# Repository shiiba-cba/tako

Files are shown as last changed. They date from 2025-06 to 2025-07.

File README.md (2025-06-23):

# tako

**tako** は、55 mm の大玉ボールを 624ZZ ベアリング 3 点支持で滑らかに駆動し、PMW3360 光学センサーと RP2040‏-Zero MCU による高精度トラッキングを備えた自作 6 ボタン・トラックボールです。アーケードコントローラー用ゲームスイッチの硬質なクリック感を持つボタンはボールの手前に配置されているため、指をボールから離さずにクリックやドラッグが可能。標準搭載のドラッグスクロール、スクロール方向切替、CPI 切替え機能により、ウェブブラウジングから CAD・DTP などの精密操作まで幅広く快適に扱えます。

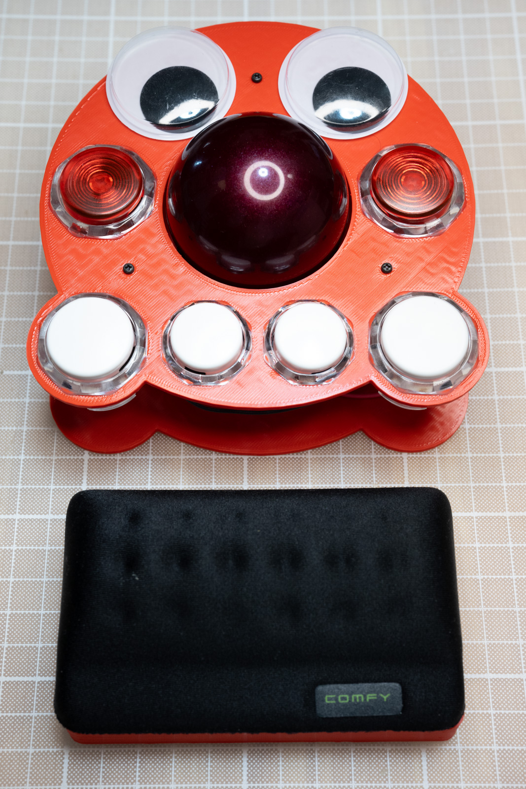
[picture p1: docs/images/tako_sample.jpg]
tako


---

## 🔧 特徴

* ボール: **55 mm径ボール**（PERIPRO-304など）
* 光学センサー: **PMW3360**（SPI）
* マイコン: **RP2040-Zero**（USB-C）
* 支持機構: **624ZZ ベアリング x3**
* ボタン: 6 ボタン（アーケードコントローラー用ゲームスイッチ 30mm×4, 24mm×2）
* ファームウェア: **QMK Firmware** ベース
* **CPI_TGL** キーコードによる CPI 切り替え（600 ↔ 200 CPI）  
  *デフォルト操作*: DRAG_SCROLL ボタンを押しながら左クリック
* **SCRL_MODE** キーコードによるスクロール方向切替（XY → Y のみ → X のみ）  
  *デフォルト操作*: DRAG_SCROLL ボタンを押しながら戻るボタン  
* ドラッグスクロール対応（XY / Y / X モード）

---

## 📦 含まれるもの

* `firmware/`: QMK ファームウェアソースおよびビルド済み `.uf2`
* `case/`: 3D プリント用 STL ファイル
* `docs/build_guide.md`: ビルドガイド（日本語）

---

## 📘 ビルドガイド

👉 [ビルドガイドはこちら](docs/build_guide.md)

---

## 🧑‍💻 ファームウェア書き込み（簡易手順）

1. RP2040-Zero の **BOOT** ボタンを押しながら USB 接続
2. 表示される `RPI-RP2` ドライブに `.uf2` ファイルをコピー
3. 自動で再起動し、USB HID デバイスとして認識されたら完了

---

## 📜 ライセンス

MIT License
Copyright © 2025 shiiba

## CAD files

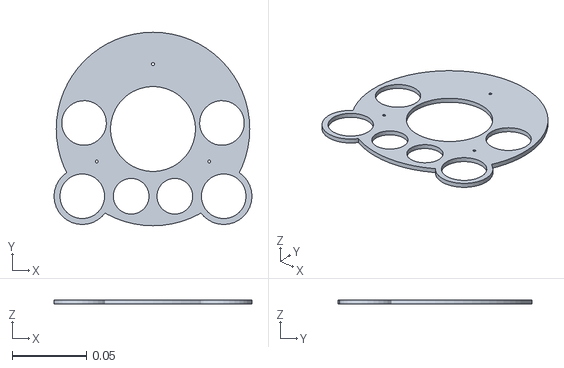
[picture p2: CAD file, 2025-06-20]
case/stl/624ZZ/tako_top_624ZZ.stl
0.133 x 0.13 x 0.003

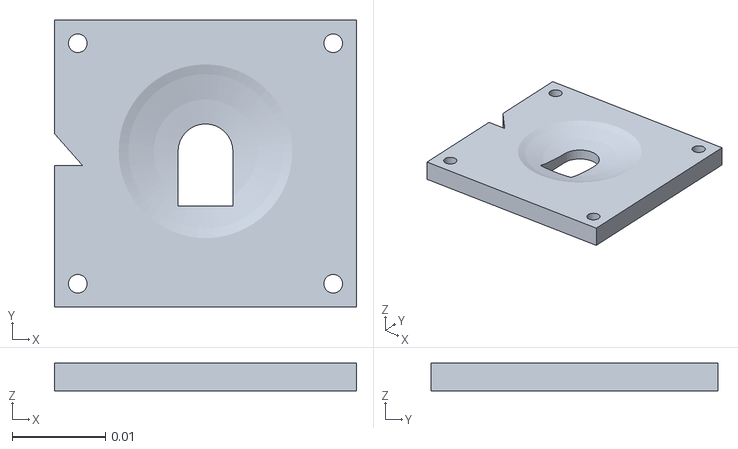
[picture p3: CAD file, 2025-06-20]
case/stl/tako_sensorcover.stl
0.0324 x 0.0308 x 0.003

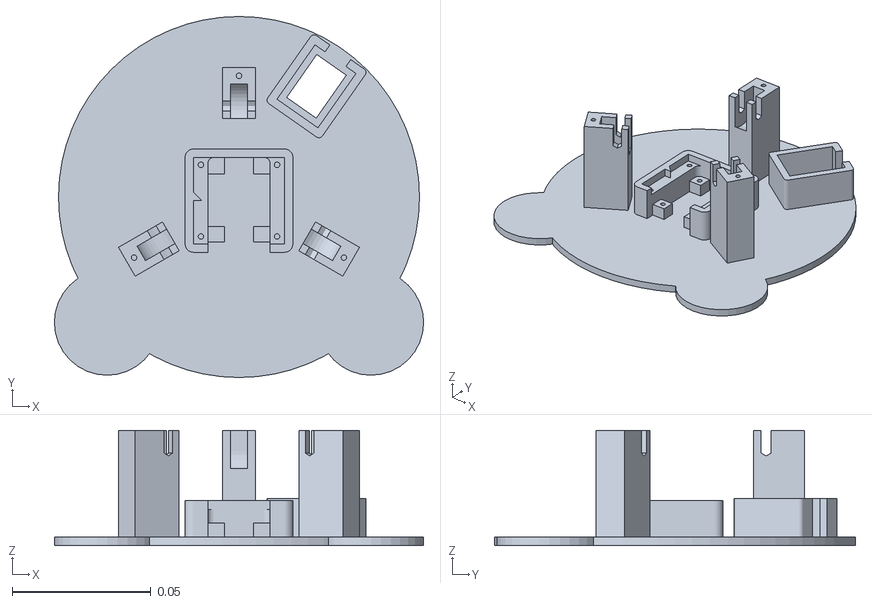
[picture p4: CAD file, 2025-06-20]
case/stl/624ZZ/tako_bottom_624ZZ.stl
0.133 x 0.13 x 0.0415

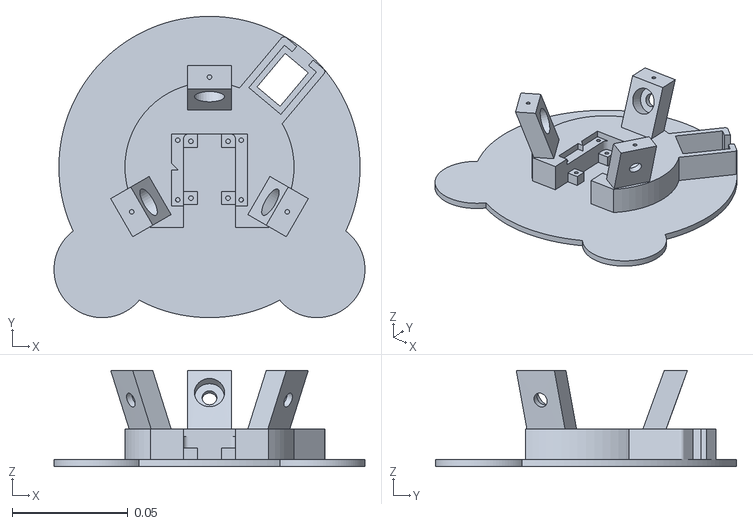
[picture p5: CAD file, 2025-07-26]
case/stl/R053010810/tako_bottom_R053010810.stl
0.134 x 0.13 x 0.0415

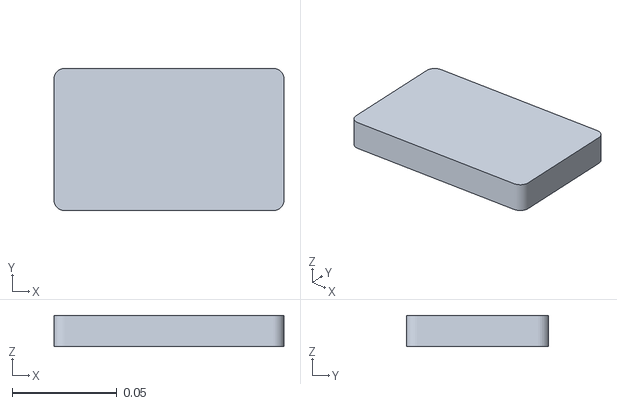
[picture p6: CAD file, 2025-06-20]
case/stl/tako_wristrest_15mm.stl
0.11 x 0.068 x 0.015

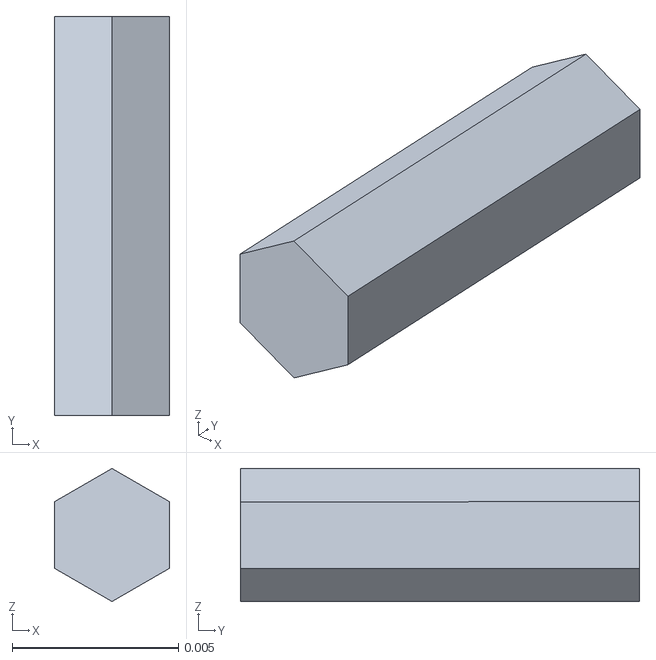
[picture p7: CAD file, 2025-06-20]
case/stl/624ZZ/tako_bearingshaft_624ZZ.stl
0.00346 x 0.012 x 0.004

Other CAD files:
case/stl/R053010810/tako_top_R053010810.stl

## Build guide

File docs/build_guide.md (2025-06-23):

# tako ビルドガイド

---

## 目次

1. [仕様概要](#1-仕様概要)
2. [必要なもの](#2-必要なもの)
3. [3D プリント設定](#3-3d-プリント設定)
4. [配線図](#4-配線図)
5. [組立手順](#5-組立手順)
6. [ファームウェア書き込み](#6-ファームウェア書き込み)
7. [動作確認](#7-動作確認)
8. [参考・謝辞](#8-参考・謝辞)
9. [ライセンス & コピーライト](#9-ライセンス--コピーライト)

---

## 1. 仕様概要

| 項目 | 内容 |
| --- | --- |
| ボール径 | **55 mm** |
| センサー | **PMW3360**（SPI 接続） |
| MCU | **RP2040‑Zero**（USB‑C） |
| ベアリング | **624ZZ** × 3（内径 4 mm / 外径 13 mm / 幅 5 mm） |
| ボタン | 6 ボタン (⌀30 mm × 4、⌀24 mm × 2) |
| ケース | 3D プリント（STL 同梱） |

---

## 2. 必要なもの
ブレイクアウト基板と3D プリント部品を除き、すべて市販品で構成されています。

### 2‑1. 電子部品

| 区分 | 品名／型番 | 個数 | 備考 |
| --- | --- | ---- | --- |
| **センサー** | **PMW3360 本体** | 1 | — |
| **ブレイクアウト基板** | **PMW3360 breakout board** | 1 | [https://github.com/jfedor2/pmw3360-breakout](https://github.com/jfedor2/pmw3360-breakout) |
| **MCU** | **RP2040‑Zero** | 1 | USB‑C |

### 2‑2. 機構部品

| 区分 | 品名 | 個数 | 備考 |
| --- | --- | ---- | --- |
| **ベアリング** | **624ZZ** | 3 | — |
| **ボタン (⌀30 mm)** | はめ込み式ゲームスイッチ | 4 | 例: GamerFinger NEW‑HBFS‑30 |
| **ボタン (⌀24 mm)** | はめ込み式ゲームスイッチ | 2 | 例: GamerFinger NEW‑HBFS‑24 |
| **ボール** | **55 mm** | 1 | 例: PERIXX PERIPRO‑304 |
| **ネジ** | M2×4 | 4 | ブレイクアウト基板固定 |
| 〃 | M2×6 | 7 | センサーカバー 4、本体 3 |
| **3D プリント部品 (STL)** | `tako_bearingshaft_624ZZ.stl` | 3 | ベアリングシャフト |
| | `tako_bottom_624ZZ.stl` | 1 | ボトムケース |
| | `tako_sensorcover.stl` | 1 | センサーカバー |
| | `tako_top_624ZZ.stl` | 1 | トップケース |
| | `tako_wristrest_15mm.stl` | 1 | （任意）リストレスト台座 |
| **リストレスト (任意)** | ELECOM COMFY MOH‑013BK | 1 | — |
| **両面テープ (任意)** | — | 適量 | リストレスト固定用 |
| **滑り止めパッド (任意)** | — | 適量 | 本体およびリストレスト台座の底面貼付・傾斜調整用 |
| **目玉シール (任意)** | 30–40 mm | 2 | トップケース装飾用 |

### 2‑3. コネクタ／ハウジング／ケーブル

| 区分 | 型番 | 個数 | 用途 |
| --- | --- | --- | --- |
| **コンタクトピン** | **QI2550 圧着端子** | 15 以上 | 予備を含め多めに準備 |
| **ハウジング 1P** | **QI2550 1P** | 5 | GND, 3V3 など |
| **ハウジング 3P** | **QI2550 3P** | 2 | 各ボタン → MCU |
| **ハウジング 4P** | **QI2550 4P** | 1 | センサー → MCU |
| **ピンヘッダー** | **1×3 (2.54 mm)** | 1 | GND 共通化用 |
| **圧着端子** | **Faston #110 (L型 / 絶縁ケース付 推奨)** | 12 以上 | ボタンスイッチ接続 |
| **ケーブル** | **AWG24 配線** | 適量 | — |
| **絶縁テープ** | — | 適量 | ピンヘッダー保護 |
| **熱収縮チューブ (任意)** | — | 適量 | ケーブル保護・束線用 |

### 2‑4. 工具

| 区分 | 名称 | 用途 |
| --- | --- | --- |
| 造形 | **3D プリンタ (FDM)** | ケース・ベアリングシャフト造形 |
| 基板実装 | 半田ごて + はんだ | センサー・ヘッダー実装 |
| 配線加工 | ニッパー | ケーブル長調整 |
| 圧着 | Faston 圧着工具 | ボタン用 Faston #110 |
| 〃 | QI2550 圧着工具 | コネクタ結線 |
| 仕上げ | プラスドライバー | M2 ネジ締結 |

---

## 3. 3D プリント設定

| パーツ | 素材 | レイヤー高 | インフィル |
| --- | ---- | --- | --- |
| すべて | PLA  | 0.20 mm | 15 % グリッド |

---

## 4. 配線図

### 4‑1. センサー

| PMW3360 | RP2040‑Zero  |
| --- | --- |
| SCLK | GPIO2 |
| MOSI | GPIO3 |
| MISO | GPIO4 |
| NCS | GPIO5 |
| 3V3 | 3V3 OUT |
| GND | GND |

### 4‑2. ボタン割り当て（デフォルト）

| ボタン | RP2040‑Zero GPIO |
| --- | --- |
| 左ボタン | GPIO14 |
| 右ボタン | GPIO27 |
| ミドルボタン | GPIO15 |
| 戻るボタン | GPIO26 |
| 進むボタン | GPIO29 |
| ドラッグスクロールボタン | GPIO28 |

### 4‑3. CPI_TGL キーコードとデフォルト操作

- **初期 CPI**: 600
- **キーコード**: `CPI_TGL`
- **デフォルト操作**: DRAG_SCROLL ボタン(GPIO28)を押しながら左ボタン(GPIO14)を押すと `CPI_TGL` が送出され、CPI が 600 ↔ 200 に切り替わります。

### 4‑4. SCRL_MODE キーコードとスクロール方向切替

`SCRL_MODE` を押すたびにスクロールモードが **XY** → **Y のみ** → **X のみ** → **XY** ... の順に循環します。
- **キーコード**: `SCRL_MODE`
- **デフォルト操作**: DRAG_SCROLL ボタン(GPIO28)を押しながら戻るボタン(GPIO26)を押すと `SCRL_MODE` が送出され、スクロール方向が切り替わります。

---

## 5. 組立手順

1. **ブレイクアウト基板の準備**  
   **PMW3360** をブレイクアウト基板へ実装し、各ピンにリード線をはんだ付けします。  
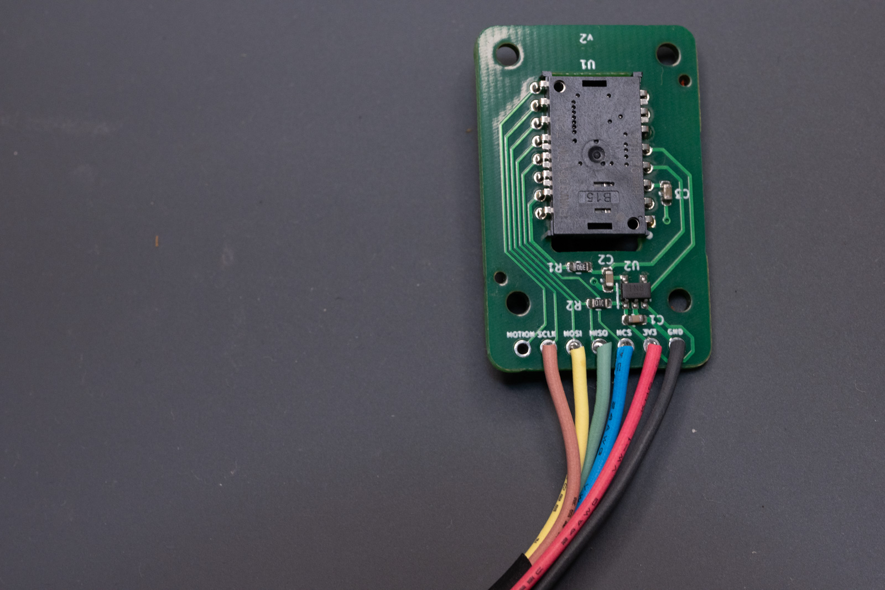
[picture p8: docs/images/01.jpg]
     
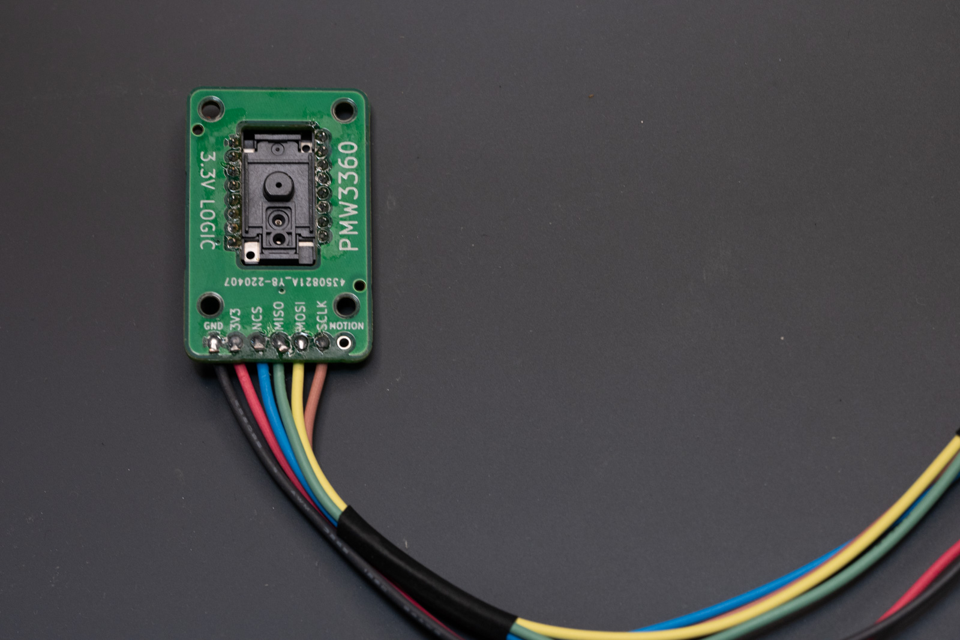
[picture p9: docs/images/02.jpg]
   
2. **GND 共通化用ピンヘッダーの準備**  
   ボタン GND をまとめるために **1×3 ピンヘッダー (2.54 mm)** をハンダブリッジして 3 ピンを共通化した "GND バス" を自作します。
   ブリッジ部は **絶縁テープ** を巻いてショートを防止します。  
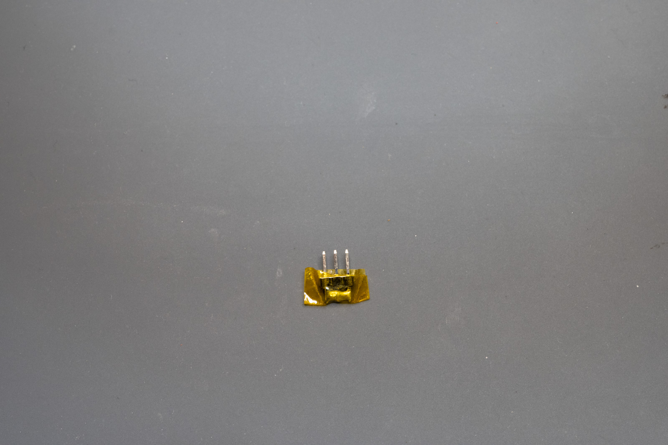
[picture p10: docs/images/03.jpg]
   
3. **ボトムケースへのセンサー固定**  
   ブレイクアウト基板を `tako_bottom_624ZZ.stl` に収め、M2×4 ネジ×4 で固定。  
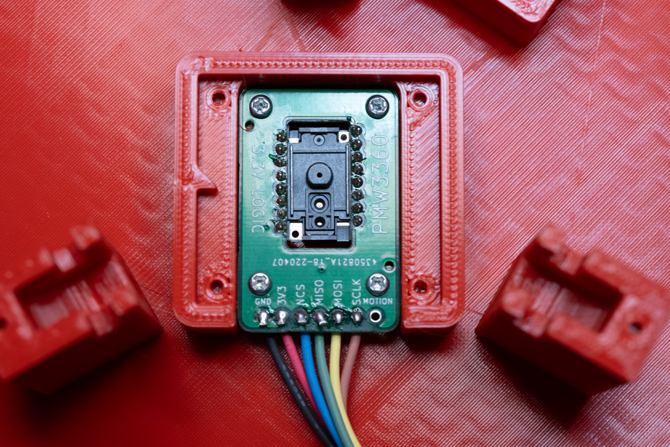
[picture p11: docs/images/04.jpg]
   
4. **レンズ & センサーカバー**  
   レンズを装着後、`tako_sensorcover.stl` を被せて M2×6 ネジ×4 で固定。  
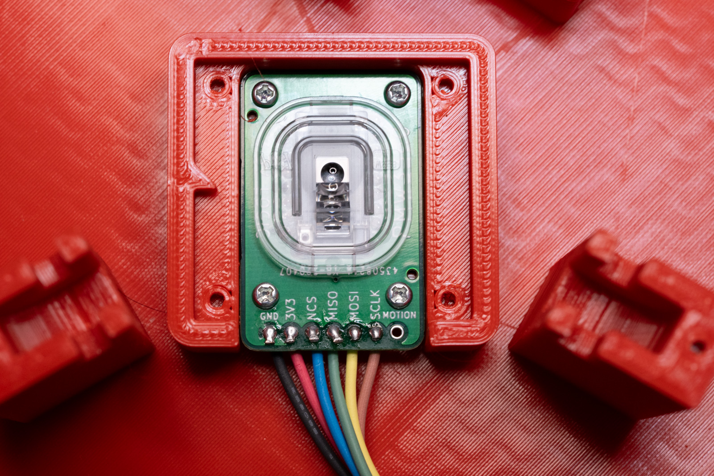
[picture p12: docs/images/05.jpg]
     
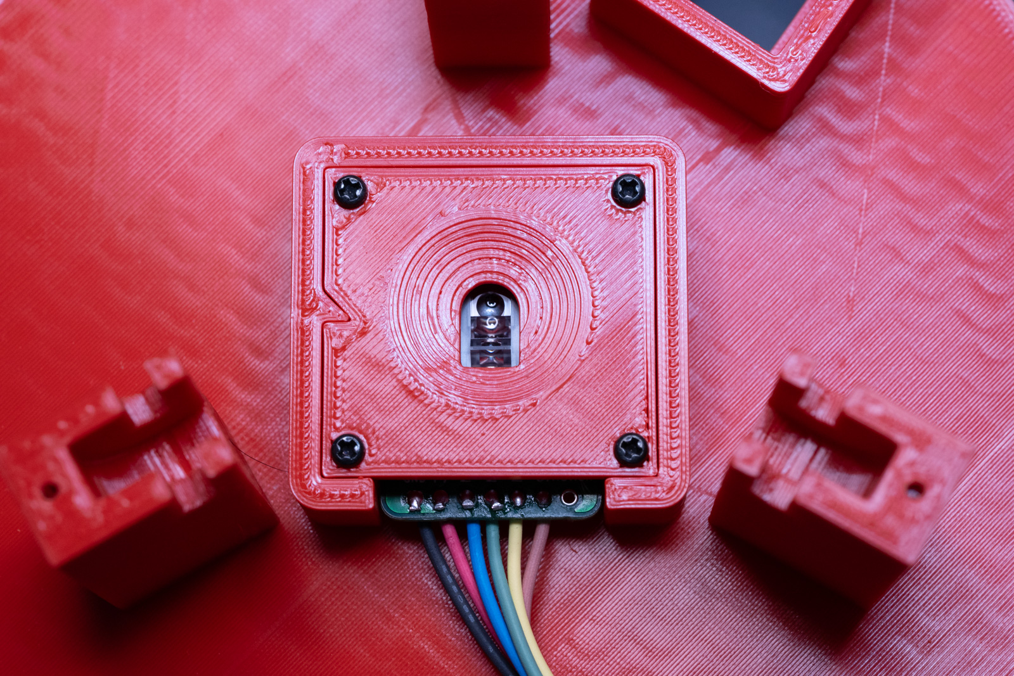
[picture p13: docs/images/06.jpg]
   
5. **ベアリングユニット作成**  
   **624ZZ** に `tako_bearingshaft_624ZZ.stl` を差し込み、3 つ用意。  
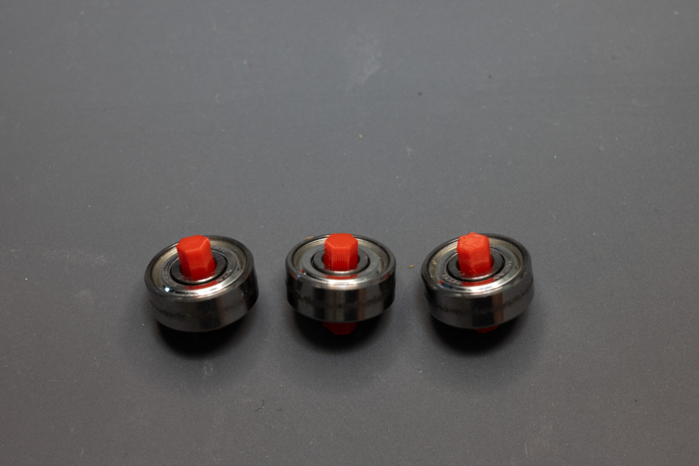
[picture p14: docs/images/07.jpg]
   
6. **支持ベアリング取付**  
   ユニットをボトムケースへ押し込み固定。  
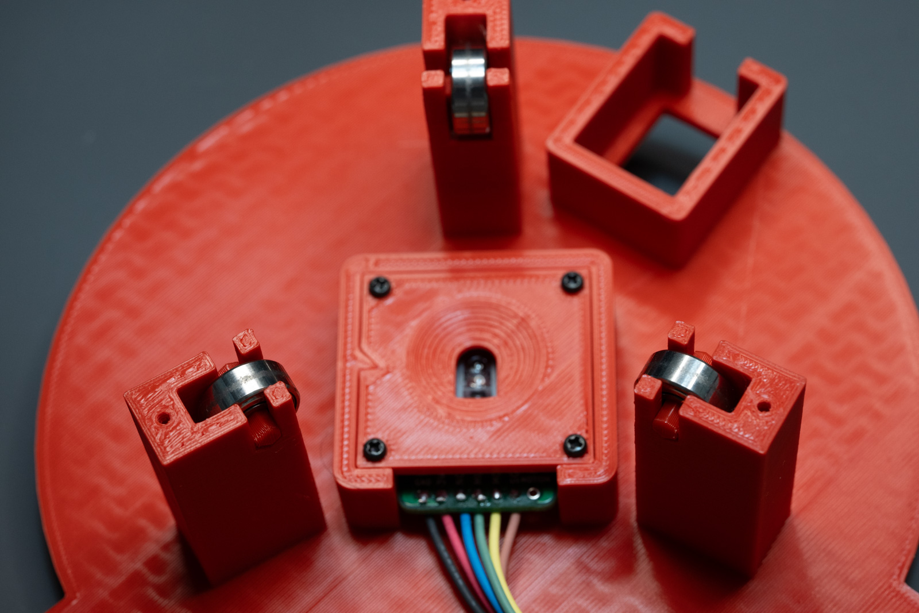
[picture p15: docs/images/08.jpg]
   
7. **MCU 取付 & 配線**  
   **RP2040‑Zero** を所定位置に差込み、センサー配線を **QI2550** コネクタ経由で接続します。  
   必要に応じて配線を束ね **熱収縮チューブ** に通し軽く炙ることで配線を整理します。  
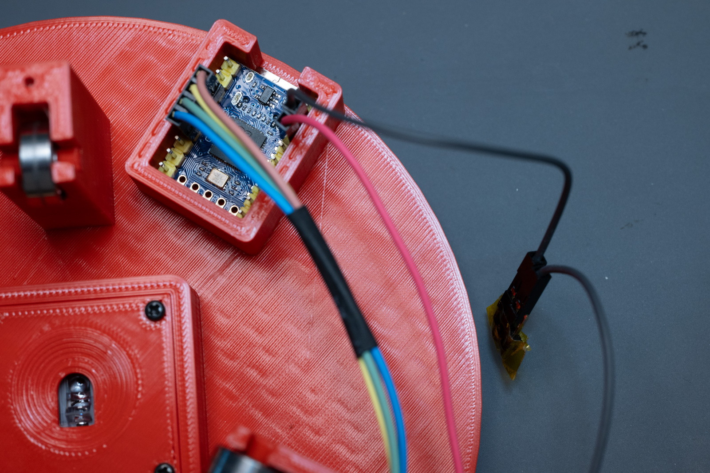
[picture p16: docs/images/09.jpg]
   
8. **トップケースにボタン実装**  
   ⌀30 mm ×4、⌀24 mm ×2 をはめ込み。  
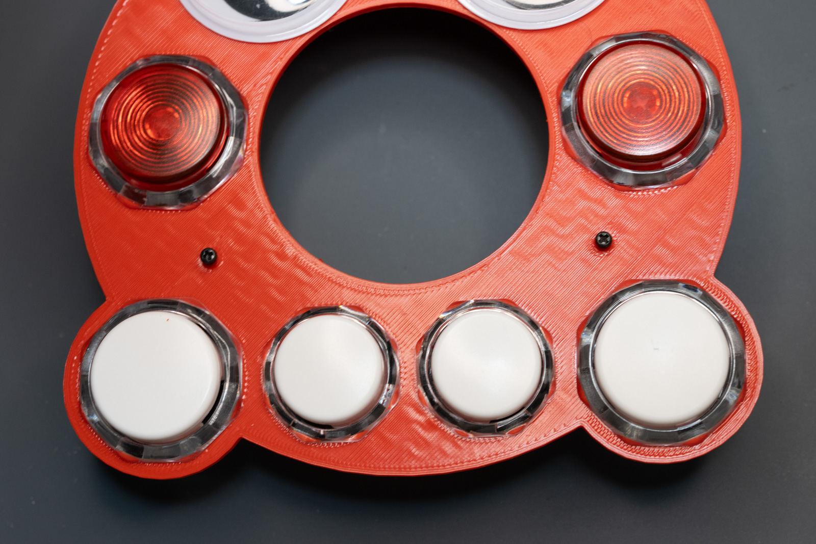
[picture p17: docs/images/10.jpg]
   
9. **ボタンの圧着・結線**  
   **Faston #110** 端子を圧着し、ボタンタブへ接続します。
   圧着後は端子全体を **絶縁ケース（熱収縮チューブや樹脂カバー）** で保護し、金属露出部がないことを確認します。  
   ケーブルは **QI2550 3P** ハウジングにまとめ、対応する MCU の GPIO へ接続してください。  
   必要に応じて配線を束ね **熱収縮チューブ** に通し軽く炙ることで配線を整理します。  
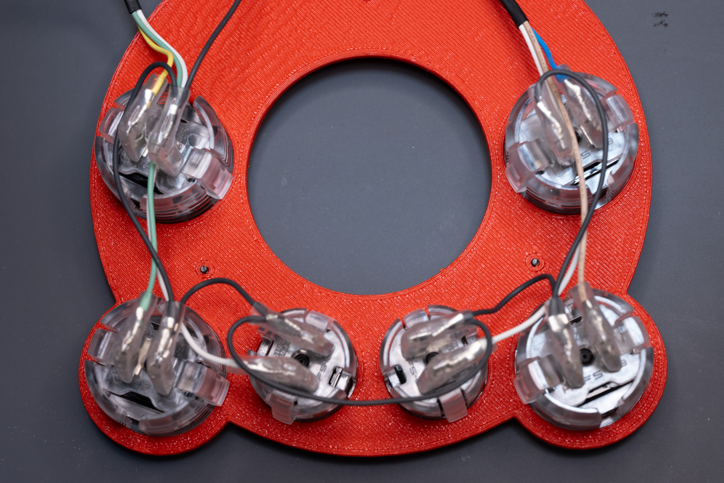
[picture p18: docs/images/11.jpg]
     
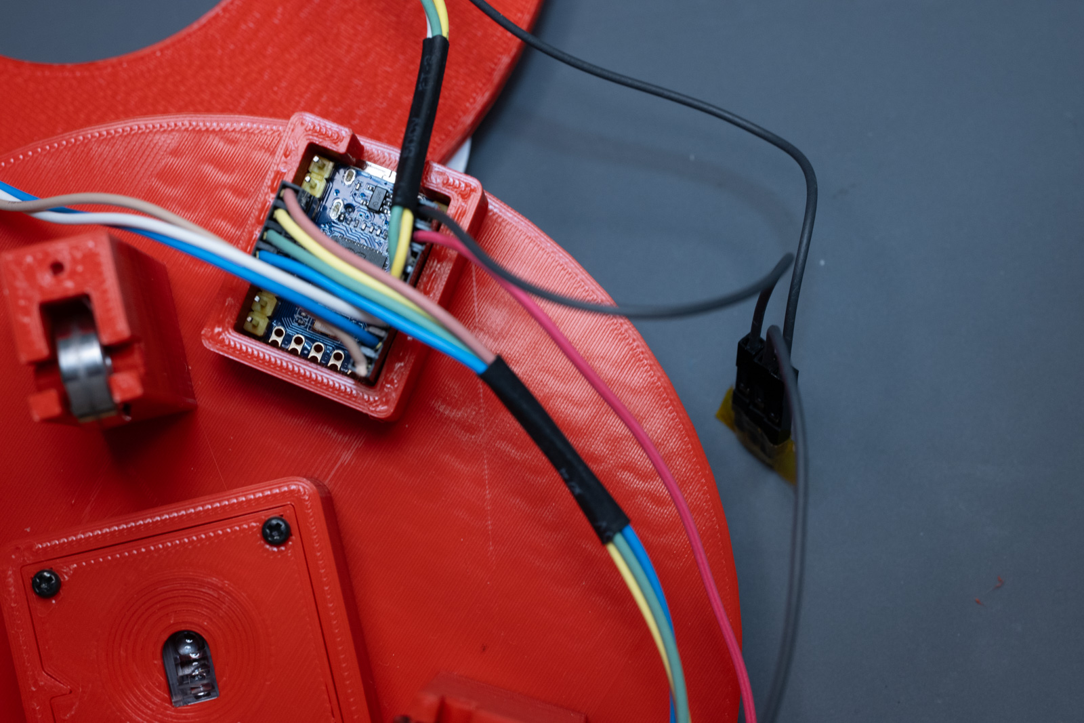
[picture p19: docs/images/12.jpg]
   
10. **ケース合体**  
    トップケースを被せ、M2×6 ネジ×3 で固定。  
    好みに合わせて 30–40 mm の目玉シールを貼り付け。  
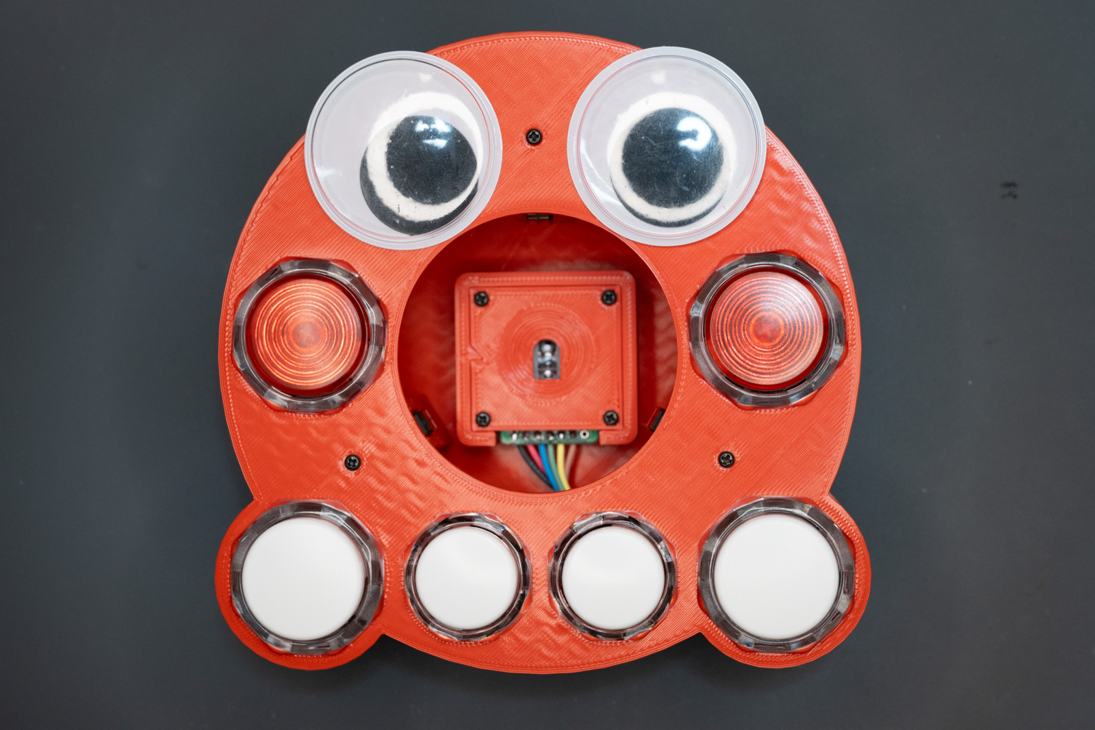
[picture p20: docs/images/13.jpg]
    
11. **滑り止めパッド貼付 (任意)**  
    底面に滑り止めパッドを貼り付け、前傾・後傾など微調整。  
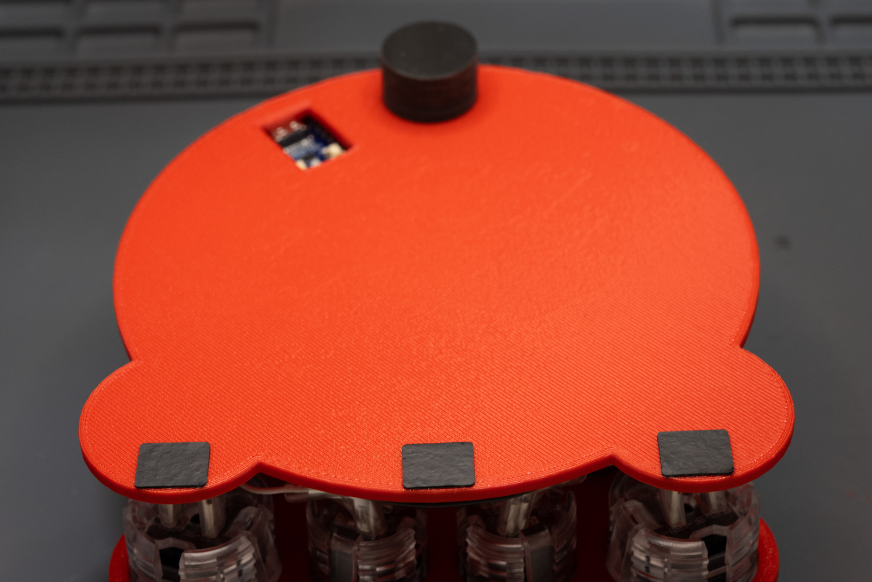
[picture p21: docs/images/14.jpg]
    
12. **リストレスト貼付 (任意)**  
    台座の上にリストレストを載せ、両面テープで固定。  
    底面に滑り止めパッドを貼り付け。  
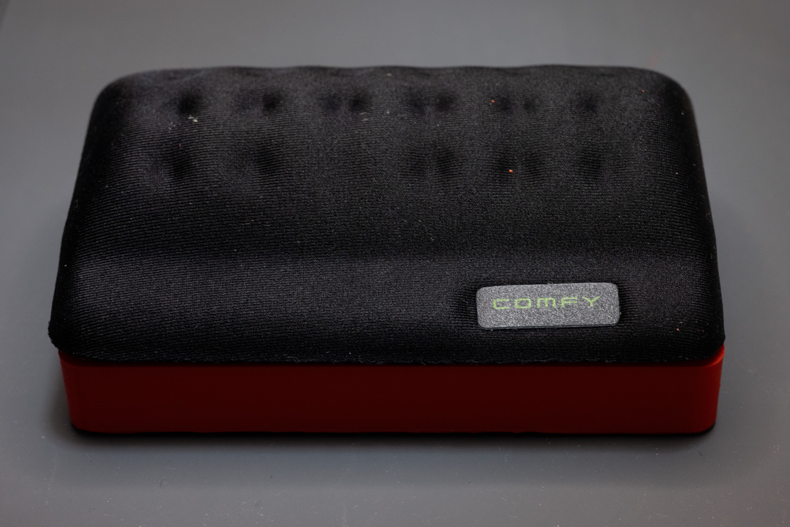
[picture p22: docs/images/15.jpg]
      
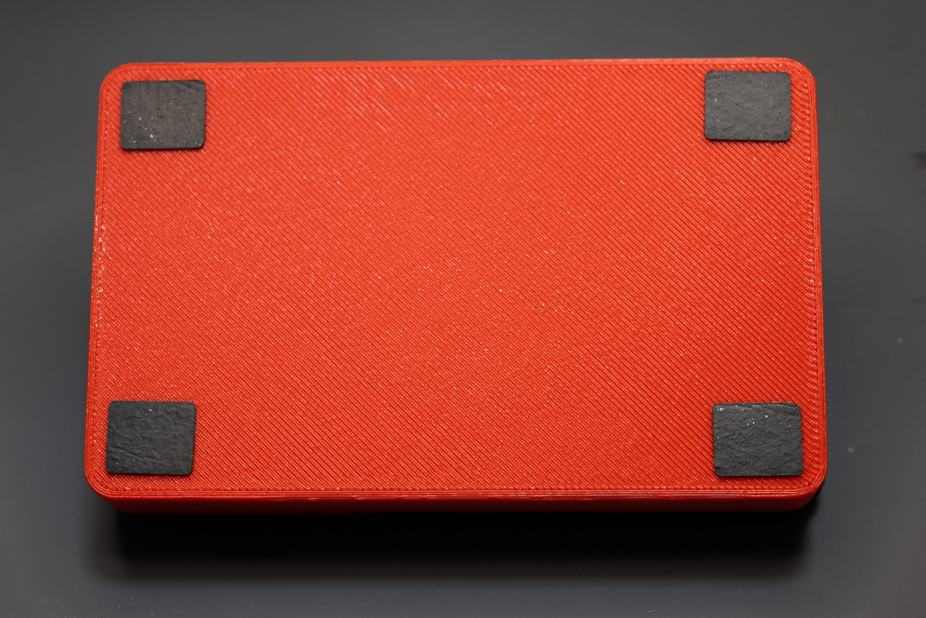
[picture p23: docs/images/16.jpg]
    
13. **完成**  
    これで完成です。お疲れ様でした。  
    tako

---

## 6. ファームウェア書き込み

1. **RP2040‑Zero** の **BOOT** ボタンを押しながら PC に **USB** 接続。
2. マウントされた **RPI‑RP2** ドライブへ `.uf2` ファイルをコピー。
3. 自動で再起動し、**USB HID デバイス**として認識されたら完了。

---

## 7. 動作確認

1. **55 mm** ボールを載せてスムーズに回転するか確認。
2. ポインタ操作や各ボタンの反応を確認。
3. ドラッグスクロールボタンを押しながらボールを動かしてスクロール確認。
4. ドラッグスクロールボタンを押しながら左クリックで CPI (600 ↔ 200) が切り替わるか確認。
5. ドラッグスクロールボタンを押しながら戻るボタンで **XY** → **Y** → **X** → ... とスクロール方向が切り替わるか確認。

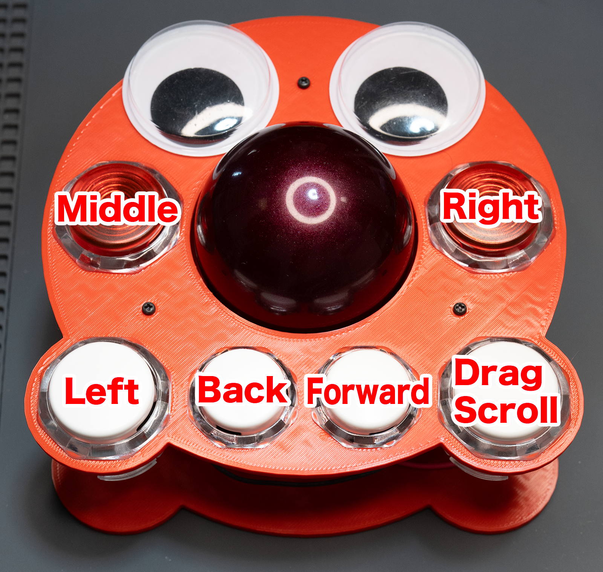
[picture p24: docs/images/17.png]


---

## 8. 参考・謝辞

* **PMW3360 Breakout Board** © jfedor2
* **QMK Firmware** © QMK Community
* 各種ライブラリ作者の皆様に感謝します。

---

## 9. ライセンス & コピーライト

本ガイドおよび付属 **STL／QMK キーマップ** は、**MIT ライセンス**で配布します。
ご自由に改変・再配布いただけますが、著作権表示の保持をお願いします。

**Copyright © 2025 shiiba**

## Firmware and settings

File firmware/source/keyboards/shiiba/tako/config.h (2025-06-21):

#pragma once

/* Direct pin configuration */
#define DIRECT_PINS { \
    { GP14, GP27, GP15, GP26, GP29, GP28 } \
}

/* Debounce reduces chatter (unintended double-presses) - set 0 if debouncing is not needed */
#define DEBOUNCE 5

/* SPI configuration for PMW3360 */
#define SPI_DRIVER SPID0
#define SPI_SCK_PIN GP2
#define SPI_MOSI_PIN GP3
#define SPI_MISO_PIN GP4
#define PMW33XX_CS_PIN GP5

/* PMW3360 settings */
#define PMW33XX_CPI 600
#define POINTING_DEVICE_INVERT_Y

/* Enable drag scroll feature */
#define POINTING_DEVICE_GESTURES_SCROLL_ENABLE

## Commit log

2025-06-20 Add UF2 and STL files
    [tako_bearingshaft_624ZZ.stl, tako_bottom_624ZZ.stl, tako_sensorcover.stl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]
2025-06-21 Refactor folders, add firmware, split docs
    [tako_bearingshaft_624ZZ.stl, tako_bottom_624ZZ.stl, tako_sensorcover.stl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]
2025-07-26 Add STL file for Bosch Rexroth R053010810
    [tako_bearingshaft_624ZZ.stl, tako_bottom_624ZZ.stl, tako_bottom_R053010810.stl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]
